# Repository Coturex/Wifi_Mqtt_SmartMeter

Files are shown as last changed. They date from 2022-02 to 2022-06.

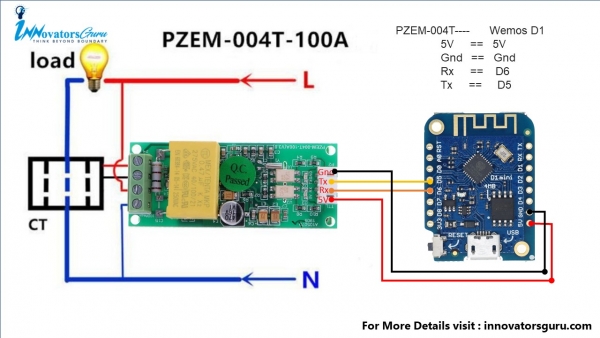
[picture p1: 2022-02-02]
doc/pzem_wemos.jpg

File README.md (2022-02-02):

# WIFI MQTT ENERGY SMARTMETER
 * **PZEM : Read Power** _Consumption (OR Production)_ - sample rate : 2s
 * Data sent to your **Domoticz** Box, raspberry, PC... using a local MQTT Broker
 
            -> data are synchronized on PZEM sample rate or DomoticzPubTimer (let see AP Webserver)
 
 * Publish **power** and **voltage** on Domotics/MQTT → _'domoticz/in'_ topic
 * Publish **all** PZEM **values** on MQTT → _'Pzem topic'_
 * Display Power/Voltage/Hz on mini screen   
 * Accuracy : ~1 % (compared to ENEDIS/Linky Webservice) - measure using Integral on Grafana (instead of Domoticz reports)
 * Wired inside Rail-DIN box




 * Wifi Access Point **WebServer** and set **custom parameters**
 * WebOTA : On The Air firmware update
        
        URL : http://<pzem_ip>:8080/update
        
        <pzem_ip> : this ip is published in the bootstrap Mqtt message ( topic : _pzem_topic_)



## Hardware requirements:   ~15 €

* PZEM Model : PZEM004T-100A v3.0   (or old v2.0)
   - PZEM-004T-v30         

* ESP Board : Wemos d1 mini (CH341 uart), esp8266
   - SoftSerial Method used on D5 D6 
   - When choosing GPIO pins to use, it's best to avoid GPIO 0, 2 and 15 (D3, D4, D8)

* Oled Shield 64x48 
   - I2C wired on D1-SCL D2-SDA

* AC-DC 5V 700mA-Small

* Plc RailDin Box ~8x37x59mm

## Wiring : 
  | Esp8266|       |PZEM004T-100A   |           |    
  |--------|-------|----------------|-----------|
  | Vcc-5V |-------|5V  (1)         |    230v-N | 
  | D5(TX) |--->---|RX  (2)         |    230v-L |    
  | D6(RX) |---<---|TX  (3)         |      Coil | 
  | GND    |-------|GND (4)         |      Coil | 
                                                                                                                               
  


# BE CARREFULL 
# ON AC/dc CONNECTIONS

## Firmware

→ https://github.com/Coturex/Wifi_Mqtt_SmartMeter/tree/main/Releases

## Domoticz settings

In domoticz you will have to activate the MQTT protocol and install (mosquitto) MQTT server on your home automation box. (raspberry or PC ...).
The power measurement (W) must then be associated with a virtual sensor
   - Type of sensor: Electric (instantaneous + counter)
   - Energy Read: * computed *
   - →  Let remember the idx of this new device, it will be informed trougth the Access Point Wifi Manager
   
## Tips

Here are different 'On_message' MQTT commands :

 Topic : 

    pzem_topic / pzem_id / cmd

|Command | Action |
|---|---|
| bs | will send an Mqtt bootstrap message |
| reboot | will reboot the device |
| ap | will start AccessPoint Settings |
| reset  | will reset Energy Counter _(only PZEM v3)_ |

## FYI  
some Linux distrib (Ubuntu 20.x) failed on connect Uart CH340/1 while flashing ESP8266

     →  "Timed out waiting for packet header"
fixed in kernels 5.13.14 and maybe upper 
(https://cdn.kernel.org/pub/linux/kernel/v5.x/ChangeLog-5.13.14)

## Todo :

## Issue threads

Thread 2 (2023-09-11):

Auriez-vous une version à plusieurs PZEM ?

renejeanmercier, 2023-09-11:
Bonjour !

Excellente réalisation que je compte bien utiliser dans mon prochain projet.

Question 1: Avez-vous travaillé sur une version à plusieurs PZEM ? Si oui auriez-vous l'amabilité de la publier ?
Question 2: Votre boitier 3D. Auriez-vous l'amabilité de  publier les fichiers sources ?

Remarque: L'hyperlien dans le Readme, retourne une erreur 404 (page non trouvée).

Merci beaucoup pour votre temps et la qualité de votre projet.

Meilleures salutations,

Rene-J

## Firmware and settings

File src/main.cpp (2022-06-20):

/*
 * Copyright (C) 2021-2022 Coturex - F5RQG
 *
 * Licensed under the Apache License, Version 2.0 (the "License");
 * you may not use this file except in compliance with the License.
 * You may obtain a copy of the License at
 *
 *      http://www.apache.org/licenses/LICENSE-2.0
 *
 * Unless required by applicable law or agreed to in writing, software
 * distributed under the License is distributed on an "AS IS" BASIS,
 * WITHOUT WARRANTIES OR CONDITIONS OF ANY KIND, either express or implied.
 * See the License for the specific language governing permissions and
 * limitations under the License.
 */

// Wemos pin use : it's best to avoid GPIO 0, 2 and 15 (D3, D4, D8)
// D5-TX : RX pzem
// D6-RX : TX pzem
// D1 : I2C clock - OLED
// D2 : I2C data  - OLED

#define FW_VERSION "1.3a"
bool DEBUG = false ;

#include <Arduino.h>
#include <ESP8266WiFi.h>
#include <WiFiClient.h>
#include <PubSubClient.h>       // Mqtt lib
#include <SoftwareSerial.h>     // ESP8266/wemos requirement
#include <WiFiManager.h>        // Manage Wifi Access Point if wifi connect failure 

#ifdef USE_OTA
#include "WebOTA.h"
#endif

//#include "myConfig_sample.h"  // Personnal settings - 'gited file'
//#include "myConfig.h"           // Personnal settings - Not 'gited file'
#include <EEPROM.h>             // EEPROM access...
#define DOMO_TOPIC "domoticz/in" 

// I2C OLED screen stuff
#ifdef USE_OLED
#define OLED_RESET 0  // GPIO0
#include "Adafruit_SSD1306.h"   // OLED requirement
Adafruit_SSD1306 display(OLED_RESET); // Wemos I2C : D1-SCL D2-SDA
#endif

// WiFi + MQTT stuff.
WiFiClient espClient ;
PubSubClient mqtt_client(espClient);  
String cmdTopic;
String outTopic;
#define MQTT_RETRY 10     // How many retries before starting AccessPoint
#define WIFI_RETRY 300    // How many retries before starting AccessPoint

// Setup our pzem module with these pins : pins must be chosen carefully so that the ESP can/cannot boot.
// Wemos : it's best to avoid GPIO 0, 2 and 15 (D3, D4, D8)
// Wemos must use softwareSerial method

// Wait this duration between each measurement (milliseconds). This is added to the time needed to read data (~2s)
int PZEM_PERIOD = 1700 ; // default PZEM wait duration (a sample rate can be added, cf domoPubTimer)
#ifdef USE_PZEM_V2
#include "PZEM004Tv20.h"      // comment if not used
PZEM004T pzem1(D6,D5);  // (RX,TX) connect to TX,RX of PZEM
IPAddress pzem_ip(192,99,1,1);
#else
#include "PZEM004Tv30.h"        // comment if not used
SoftwareSerial pzemSWSerial1(D6, D5);
PZEM004Tv30 pzem1 ; // pzemSWSerial1(RX,TX) connect to TX,RX of PZEM
#endif

//  ACCESS POINT
bool TEST_CP         = false; // AP : always start the ConfigPortal, even if ap found
bool ALLOWONDEMAND   = true;  // AP : enable on demand - e.g Trigged on Gpio Input, On Mqtt Msg etc...

#define MAX_STRING_LENGTH 35         
struct { 
    char name[MAX_STRING_LENGTH] = "";
    char mqtt_server[MAX_STRING_LENGTH] = "";
    char mqtt_port[MAX_STRING_LENGTH] = "";
    char pzem_topic[MAX_STRING_LENGTH] = "";
    char pzem_id[MAX_STRING_LENGTH] = "";
    char pzem_srate[MAX_STRING_LENGTH] = "";    
    char idx_power[MAX_STRING_LENGTH] = "";
    char idx_voltage[MAX_STRING_LENGTH] = "";
    int  domoPubTimer = 0;
    int  AP = 0 ;
  } settings;

struct {
    float voltage = 0 ;
    float current = 0 ;
    float power = 0 ;
    float energy = 0 ;
    float frequency = 0 ;
    float pf= 0;
    float powerAvg = 0 ;
    bool  read_error = false ;
    int   err_count = 0 ;
    int   read_count = 0 ;
    float ppm_err = 0 ;
} pzemValues ;

WiFiManager wm;
WiFiManagerParameter custom_name("name", "Oled Title", "", 15);
WiFiManagerParameter custom_mqtt_server("mqtt_server", "mqtt IP server", "", 15);
WiFiManagerParameter custom_mqtt_port("mqtt_port", "mqtt Port", "", 4);
WiFiManagerParameter custom_pzem_topic("pzem_topic", "Pzem Topic", "", 35);
WiFiManagerParameter custom_pzem_id("pzem_id", "Pzem ID", "", 15);
WiFiManagerParameter custom_pzem_srate("pzem_srate", "Pzem srate (s >1500)", "", 5);
WiFiManagerParameter custom_idx_power("idx_power", "Domoticz idx power", "", 4); 
WiFiManagerParameter custom_idx_voltage("idx_volt", "Domoticz idx voltage", "", 4);
WiFiManagerParameter custom_domoPubTimer("domoPubTimer", "Domoticz publish timer (s)", "", 4);

// domoPubTimer is Used to reduce telemetry sent to Domoticz/InfluxDb
//      if empty -> synchronise Domoticz publication on PZEM sample rate
//      if x sec -> Domoticz publication every x seconds (Power is then averaged). 

#ifdef USE_OLED
void oled_cls(int size) {
    // OLED : set cursor on top left corner and clear
    display.clearDisplay();
    display.setTextSize(size);
    display.setTextColor(WHITE); // seems only WHITE exist on this oled model :(
    display.setCursor(0,0);
}
#endif

void read_Settings () { // From EEPROM
    unsigned int addr=0 ;  
    //Serial.println("[READ EEPROM] read_Settings");  
    EEPROM.get(addr, settings); //read data from array in ram and cast it to settings
    Serial.println("[READ EEPROM] Oled name : " + String(settings.name) ) ;
    Serial.println("[READ EEPROM] mqtt_server : " + String(settings.mqtt_server) ) ;
    Serial.println("[READ EEPROM] mqtt_port : " + String(settings.mqtt_port) ) ;
    Serial.println("[READ EEPROM] pzem_topic : " + String(settings.pzem_topic) ) ;
    Serial.println("[READ EEPROM] pzem_id : " + String(settings.pzem_id) ) ;
    Serial.println("[READ EEPROM] pzem_srate : " + String(settings.pzem_srate) ) ;
    Serial.println("[READ EEPROM] idx_power : " + String(settings.idx_power) ) ;
    Serial.println("[READ EEPROM] idx_voltage : " + String(settings.idx_voltage) ) ;
    Serial.println("[READ EEPROM] domoPubTimer   : " + String(settings.domoPubTimer) ) ;
    }

void write_Settings() { // write to EEPROM
    unsigned int addr=0 ;
    EEPROM.put(addr, settings); //write data to array in ram 
    EEPROM.commit();  // write data from ram to flash memory. Do nothing if there are no changes to EEPROM data in ram
}

void saveWifiCallback() { // Save settings to EEPROM
    String srate_str ;
    read_Settings();
    Serial.println("[CALLBACK] saveParamCallback fired"); 
    // Field statint with '.' is ignored, value is not updated
    if (custom_name.getValue()[0] != '.') { 
        strncpy(settings.name, custom_name.getValue(), MAX_STRING_LENGTH);  
    }
    if (custom_mqtt_server.getValue()[0] != '.') { 
    strncpy(settings.mqtt_server, custom_mqtt_server.getValue(), MAX_STRING_LENGTH);  
    }
    if (custom_mqtt_port.getValue()[0] != '.') { 
        strncpy(settings.mqtt_port, custom_mqtt_port.getValue(), MAX_STRING_LENGTH);  
    }
    if (custom_pzem_topic.getValue()[0] != '.') { 
        strncpy(settings.pzem_topic, custom_pzem_topic.getValue(), MAX_STRING_LENGTH);  
    }
    if (custom_pzem_id.getValue()[0] != '.') { 
        strncpy(settings.pzem_id, custom_pzem_id.getValue(), MAX_STRING_LENGTH);  
    }
    if (custom_pzem_srate.getValue()[0] != '.') { 
        strncpy(settings.pzem_srate, custom_pzem_srate.getValue(), MAX_STRING_LENGTH);  
    }
    if (custom_idx_power.getValue()[0] != '.') { 
        strncpy(settings.idx_power, custom_idx_power.getValue(), MAX_STRING_LENGTH);  
    }
    if (custom_idx_voltage.getValue()[0] != '.') { 
        strncpy(settings.idx_voltage, custom_idx_voltage.getValue(), MAX_STRING_LENGTH);
    }
    if (custom_domoPubTimer.getValue()[0] != '.') { 
        char timerChar[MAX_STRING_LENGTH] = "";
        strncpy(timerChar, custom_domoPubTimer.getValue(), MAX_STRING_LENGTH);
        settings.domoPubTimer = String(timerChar).toInt() * 1000 ;
    }
    settings.AP = 0 ;  
    write_Settings() ;    
}

void wifi_connect (int retry) {
    // Wait for connection (even it's already done)
    while (WiFi.status() != WL_CONNECTED) {
        #ifdef USE_OLED
        oled_cls(1);
        display.println("Connecting");
        display.println("wifi (" + String(retry)+")");  
        display.display();
        #endif
        Serial.print(".");
        delay(1000); // 1s
        retry --;
        if (retry < 0) { // wifi timeout 
            ESP.restart() ;
        }
    }

    Serial.println("");
    Serial.print("Wifi Connected");
    Serial.println("");
    Serial.print("Connected to Network : ");
    Serial.println(WiFi.localIP());  //IP address assigned to ESP
    #ifdef USE_OLED
    oled_cls(1);
    display.println("Wifi on");
    display.println(WiFi.localIP());
    display.display();
    #endif
}

void setup_wifi () {
    delay(10);
    WiFi.mode(WIFI_STA); // explicitly set mode, esp defaults to STA+AP   
    // WiFi.setSleepMode(WIFI_NONE_SLEEP); // disable sleep, can improve ap stability
    // wm.debugPlatformInfo();
    //reset settings - for testing
    // wm.resetSettings();
    // wm.erase();  
    WiFi.softAPdisconnect(true) ;
    // setup some parameters
    WiFiManagerParameter custom_html("<p>EEPROM Custom Parameters</p>"); // only custom html
    wm.addParameter(&custom_html);
    wm.addParameter(&custom_name);   
    wm.addParameter(&custom_mqtt_server);
    wm.addParameter(&custom_mqtt_port);
    wm.addParameter(&custom_pzem_topic);
    wm.addParameter(&custom_pzem_id);
    wm.addParameter(&custom_pzem_srate);
    wm.addParameter(&custom_idx_power);
    wm.addParameter(&custom_idx_voltage);
    wm.addParameter(&custom_domoPubTimer);
    // callbacks
    //wm.setAPCallback(configModeCallback);
    wm.setSaveConfigCallback(saveWifiCallback);
    wm.setBreakAfterConfig(true); // needed to use saveWifiCallback
    
    // set values later if I want
    // custom_html.setValue("test",4);
    // custom_token.setValue("test",4);

    //sets timeout until configuration portal gets turned off
    //useful to make it all retry or go to sleep in seconds
    String apName ;
    int AP_TIMEOUT = 60 ;
    wm.setTimeout(AP_TIMEOUT) ;
        //wm.setConnectTimeout(AP_TIMEOUT);
    WiFi.printDiag(Serial);
    apName = "pzem_AP_" + String(settings.name) + "_" + String(ESP.getChipId()) ; 
    if(!wm.autoConnect(apName.c_str(),"admin")) {
        Serial.println("AP : " + apName +"- no connection, timeout");
    } 
    else if(TEST_CP or settings.AP) {
        // start configportal always
        delay(1000);
        apName = "pzem_AP_" + String(settings.name) ;
        wm.setConfigPortalTimeout(AP_TIMEOUT); // run AccessPoint for .. s
        switch (settings.AP) {
            case 1: 
                apName = "req_pzem_AP_" +String(settings.pzem_id) ;
                Serial.println("AP Config Portal : requested on topic/cmd");
                wm.startConfigPortal(apName.c_str()) ;
                Serial.println("---- End of request-AP") ;
                settings.AP = 0 ;   
                write_Settings();
                ESP.restart() ;
                break ;
            case 2:    
                apName = "mqtt_pzem_AP_" +String(settings.pzem_id) ;
                Serial.println("AP Config Portal : mqtt connection failure");
                wm.startConfigPortal(apName.c_str()) ;
                Serial.println("---- End of mqtt-AP") ;
                settings.AP = 0 ;
                write_Settings();                
                ESP.restart() ;
                break ;
        } 
    }
    else {
        //Here connected to the WiFi
        Serial.println("connected...yeaaa :)");
    }
    WiFi.printDiag(Serial);
}

bool mqtt_connect(int retry) {
    bool ret = false ;
    while (!mqtt_client.connected() && WiFi.status() == WL_CONNECTED && retry) {
        String clientId = "pzem-"+String(settings.pzem_id);
        Serial.print("[mqtt_connect] (re)connecting (" + String(retry) + " left) ") ;
        retry--;
        Serial.println("[mqtt_connect]"+String(settings.mqtt_server)+":"+String(settings.mqtt_port)) ; 
        #ifdef USE_OLED
        oled_cls(1);
        display.println("Connecting");
        display.println("mqtt (" + String(retry)+")");  
        display.println("idx_p :" + String (settings.idx_power) );
        display.println("idx_v :" + String (settings.idx_voltage) );
        display.display();
        #endif
        if (!mqtt_client.connect(clientId.c_str())) {
            ret = false ;
            delay(5000);
        } else {
            ret = true ;
            Serial.println("[mqtt_connect] Subscribing : "+ cmdTopic) ; 
            delay(2000);
            mqtt_client.subscribe(cmdTopic.c_str());
        }
    }
    return ret ;
}

void bootPub() {
        String  msg = "{ \"type\": pzem";	
                msg += ", \"id\": ";
                msg += String(settings.pzem_id) ;
                msg += ", \"fw_version\": ";
                msg += String(FW_VERSION) ;
                msg += ", \"chip_id\": ";
                msg += String(ESP.getChipId()) ;
                msg += ", \"pzem_version\": ";
                #ifdef USE_PZEM_V2
                msg += "v2" ;
                #else
                msg += "v3" ;
                #endif         
                msg += ", \"srate\": ";
                msg += String(PZEM_PERIOD) ;      
                msg += ", \"pzem_idx1\": ";
                msg += String(settings.idx_power) ;
                msg += ", \"pzem_idx2\": ";
                msg += String(settings.idx_voltage) ;
                msg += ", \"DomoPubTimer\": ";
                msg += String(settings.domoPubTimer/1000) ;
                msg += ", \"ip\": ";  
                msg += WiFi.localIP().toString().c_str() ;
                msg += "}" ;
        String bootSuffix = "" ;
        if (DEBUG) { Serial.println("Sending Bootstrap on topic : " + String(settings.pzem_topic)+ bootSuffix);}
        mqtt_client.publish((String(settings.pzem_topic)+ bootSuffix).c_str(), msg.c_str()); 
}

void domoPub(String idx, float value) {
    if (idx.toInt()> 0) {
      String msg = "{ \"idx\": ";	 // {"idx": 209, "nvalue": 0, "svalue": "2052"}
      msg += idx;
      msg += ", \"nvalue\": 0, \"svalue\": \"";
      msg += value ;
      msg += "\"}";

      String domTopic = DOMO_TOPIC;             // domoticz topic
      if (DEBUG) {
        Serial.println("domoPub on topic : " + domTopic);
        Serial.println("domoPub : " + msg);
      }   
      mqtt_client.publish(domTopic.c_str(), msg.c_str()); 
    }
}

void statusPub() {
    String msg ;
    if (pzemValues.read_error) {
        msg = "{ \"PZEM_READ_ERROR\": ";
        msg += String(pzemValues.err_count);
        msg += ", \"pzem_read \": ";  
        msg += String(pzemValues.read_count) ;    
        msg += ", \"ppm_err\": ";  
        msg += String(pzemValues.ppm_err) ;    
        msg += "}";
    } else {
        msg = "{ ";
        msg += "\"voltage\": ";
        msg += String( (pzemValues.voltage < 0) ? 0 : pzemValues.voltage ) ;
        msg += ", \"current\": ";
        msg += String( (pzemValues.current < 0) ? 0 : pzemValues.current );
        msg += ", \"power\": ";
        msg += String( (pzemValues.power < 0) ? 0 : pzemValues.power );
        msg += ", \"energy\": ";
        msg += String( (pzemValues.energy < 0) ? 0 : pzemValues.energy );
        msg += ", \"frequency\": ";
        msg += String(pzemValues.frequency);
        msg += ", \"powerfactor\": ";
        msg += String(pzemValues.pf);
        /*msg += "{ \"PZEM_READ_ERROR\": ";
        msg += String(pzemValues.err_count);
        msg += ", \"pzem_read \": ";  
        msg += String(pzemValues.read_count) ;   
        */ 
        msg += ", \"ppm_err\": ";  
        msg += String(pzemValues.ppm_err) ;    
        msg += "}";
    }
    String topic = String(settings.pzem_topic)+"/"+String(settings.pzem_id) ;
    if (DEBUG) {
        Serial.println("statusPub on topic : " + topic);
        Serial.println("statusPub : " + msg);
      } 
    mqtt_client.publish(String(topic).c_str(), msg.c_str()); 
}

void rebootOnAP(int ap){
        Serial.println("Force Rebooting on Acess Point");
        settings.AP = ap ;
        write_Settings() ;    
        ESP.restart();
}

void on_message(char* topic, byte* payload, unsigned int length) {
    if (DEBUG) { Serial.println("Receiving msg on topic : " + String(topic));}; 
    char buffer[length+1];
    memcpy(buffer, payload, length);
    buffer[length] = '\0';
    if (DEBUG) { Serial.println("  msg : {" + String(buffer) + "}");}; 
    if (String(buffer) == "bs") { // Bootstrap is requested
            if (DEBUG) { Serial.println("     Bootstrap resquested") ; } ;
            bootPub();
    } else if (String(buffer) == "ap") { // AccessPoint is requested
            if (DEBUG) { Serial.println("     AccessPoint resquested") ; } ;
            rebootOnAP(1);
    } else if (String(buffer) == "reboot") { // Reboot is requested
            if (DEBUG) { Serial.println("     Reboot resquested") ; } ;
            ESP.restart(); 
    } else if (String(buffer) == "reset") { // Reset Energy counter is requested
            #ifdef USE_PZEM_V3
            if (DEBUG) { Serial.println("     Reset Energy resquested") ; } ;
            pzem1.resetEnergy()   ;
            #endif
    } else {
        if (DEBUG) { Serial.println("     Nothing to do") ; } ;
    }
}

void setup() {  
    randomSeed(micros());  // initializes the pseudo-random number generator
    Serial.begin(115200);

    #ifdef USE_PZEM_V2
    pzem1.setAddress(pzem_ip);
    #else // USE PZEM V3
    pzem1 = PZEM004Tv30(pzemSWSerial1) ; 
    //pzem1.resetEnergy()    ;
    #endif

    #ifdef USE_OLED
    // OLED Shield 
    display.begin(SSD1306_SWITCHCAPVCC, 0x3C);  // initialize with the I2C addr 0x3C (for the 64x48)
    display.display(); 
    #endif
    
    //load eeprom data (sizeof(settings) bytes) from flash memory into ram
    EEPROM.begin(sizeof(settings));
    Serial.println("[setup] EEPROM size: " + String(sizeof(settings)) + " bytes");
    read_Settings(); // read EEPROM
    PZEM_PERIOD = String(settings.pzem_srate).toInt() ;
    if (PZEM_PERIOD < 1000) {
        PZEM_PERIOD = 1000 ;
    } 
    Serial.println("[setup] PZEM_PERIOD : "+ String(PZEM_PERIOD));
    setup_wifi() ;
    delay(5000) ;
    uint16_t port ;
    char *ptr ;
    port = strtoul(settings.mqtt_port,&ptr,10) ;
    cmdTopic = String(settings.pzem_topic) + "/" + String(settings.pzem_id) +"/cmd";  //e.g topic :regul/vload/id-00/cmd
    outTopic = String(settings.pzem_topic) + "/" + String(settings.pzem_id) ;         //e.g topic :regul/vload/id-00/

    mqtt_client.setServer(settings.mqtt_server, port); // data will be published
    mqtt_client.setCallback(on_message); // subscribing/listening mqtt cmdTopic
    // OTA 
    #ifdef USE_OTA
    webota.init(8080,"/update"); // Init WebOTA server 
    #endif
}

bool readPZEM(){
    pzemValues.read_error = false ;
    pzemValues.read_count += 1 ;
    #ifdef USE_PZEM_V2
        pzemValues.voltage = pzem1.voltage(pzem_ip);
        pzemValues.current = pzem1.current(pzem_ip);
        pzemValues.power = pzem1.power(pzem_ip);
        pzemValues.energy = pzem1.energy(pzem_ip);
        pzemValues.frequency = 0 ;
        pzemValues.pf = 0 ;
    #else // USE PZEM V3
    if (DEBUG) {
        Serial.print("[readPZEM] PZEM-1 Custom Address:");
        Serial.println(pzem1.readAddress(), HEX);
    }
        pzemValues.power = pzem1.power();
        pzemValues.voltage = pzem1.voltage();
        pzemValues.current = pzem1.current();
        pzemValues.energy = pzem1.energy();
        pzemValues.frequency = pzem1.frequency();
        pzemValues.pf = pzem1.pf(); 
    #endif
    if (DEBUG) {
    Serial.print("[readPZEM] 1-Puissance : ") ;
    Serial.println(pzemValues.power);
    Serial.print("[readPZEM] 1-Volt : ") ;
    Serial.println(pzemValues.voltage);
    }
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
void loop() {
    unsigned long loopTime = millis() ;
    if (DEBUG) {Serial.println("--") ;} ;
    if (WiFi.status() != WL_CONNECTED) {
        wifi_connect(WIFI_RETRY);
    }
    if (!mqtt_client.connected() && WiFi.status() == WL_CONNECTED ) {
       if (mqtt_connect(MQTT_RETRY)) { 
           bootPub();
        } else {
            if (WiFi.status() == WL_CONNECTED) {
	      if (DEBUG) {Serial.println("-- mqtt retry reached, rebooting...") ;} ;
	      rebootOnAP(2);
            }
        }
    }
    mqtt_client.loop(); // seems it blocks for 100ms
    
    if (readPZEM()) {
        countLoopDomoPubTimer++ ;
        if (settings.domoPubTimer > PZEM_PERIOD) { // domoPubTimer settings is not Empty,  PowerAvg is used
            pzemValues.powerAvg += pzemValues.power ;
            spendTimeDomoPubTimer = millis() - startLoopDomoPubTimer ;
            if (DEBUG) { Serial.println("spendTimeDomoPubTimer : " + String(spendTimeDomoPubTimer)) ;} ; 
            if (spendTimeDomoPubTimer >=  settings.domoPubTimer) {
                domoPub(String(settings.idx_power),pzemValues.powerAvg/countLoopDomoPubTimer); 
                domoPub(String(settings.idx_voltage),pzemValues.voltage);  // last read voltage value is enough (unaveraged)
                startLoopDomoPubTimer = millis();
                countLoopDomoPubTimer = 0 ;
                pzemValues.powerAvg = 0 ;
            }
        } else { // Pzem Standard sample rate is used to publish on Domoticz topic
            domoPub(String(settings.idx_power),pzemValues.power);
            domoPub(String(settings.idx_voltage),pzemValues.voltage);            
        }
    } ;

    statusPub();

    #ifdef USE_OTA
    webota.handle(); 
    webota.delay(PZEM_PERIOD);
    #else
    delay(PZEM_PERIOD) ;
    #endif

    if (DEBUG) {
        Serial.print("loop time (ms) : ") ;
        Serial.println((millis()-loopTime)); // print spare time in loop 
        }   
}

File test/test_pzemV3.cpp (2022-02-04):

#include <Arduino.h>
#include <SoftwareSerial.h>

#include "PZEM004Tv30.h"

#if defined(ESP32)
    #error "Software Serial is not supported on the ESP32"
#endif

SoftwareSerial pzemSWSerial(D5,D6); // pzemSWSerial(PZEM_RX_PIN, PZEM_TX_PIN);

PZEM004Tv30 pzem(pzemSWSerial);

void setup() {
    /* Debugging serial */
    Serial.begin(115200);
}

void loop() {
         
    Serial.print("Custom Address:");
    Serial.println(pzem.readAddress(), HEX);

    // Read the data from the sensor
    float voltage = pzem.voltage();
    float current = pzem.current();
    float power = pzem.power();
    float energy = pzem.energy();
    float frequency = pzem.frequency();
    float pf = pzem.pf();

    // Check if the data is valid
    if(isnan(voltage)){
        Serial.println("Error reading voltage");
    } else if (isnan(current)) {
        Serial.println("Error reading current");
    } else if (isnan(power)) {
        Serial.println("Error reading power");
    } else if (isnan(energy)) {
        Serial.println("Error reading energy");
    } else if (isnan(frequency)) {
        Serial.println("Error reading frequency");
    } else if (isnan(pf)) {
        Serial.println("Error reading power factor");
    } else {

        // Print the values to the Serial console
        Serial.print("Voltage: ");      Serial.print(voltage);      Serial.println("V");
        Serial.print("Current: ");      Serial.print(current);      Serial.println("A");
        Serial.print("Power: ");        Serial.print(power);        Serial.println("W");
        Serial.print("Energy: ");       Serial.print(energy,3);     Serial.println("kWh");
        Serial.print("Frequency: ");    Serial.print(frequency, 1); Serial.println("Hz");
        Serial.print("PF: ");           Serial.println(pf);
    }

    Serial.println();
    delay(2000);
}

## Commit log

2021-10-30 add fritz
    [pzem_mqtt.fzz]
2022-01-27 add Domoticz publish timer / PowerAvg
2022-01-28 on_message : add reboot/reset_energy
    [main.cpp]
2022-02-04 add pzem v1
    [pzem_mqtt.fzz]
2022-03-17 reverse TX RX zpemV3 as defined on V2
    [main.cpp]
2022-11-14 add current sensor doc
    [current_sensor.fzz]
